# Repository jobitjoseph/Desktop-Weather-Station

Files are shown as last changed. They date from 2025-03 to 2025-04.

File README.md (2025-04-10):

# [Desktop-Weather-Station](https://circuitdigest.com/microcontroller-projects/)

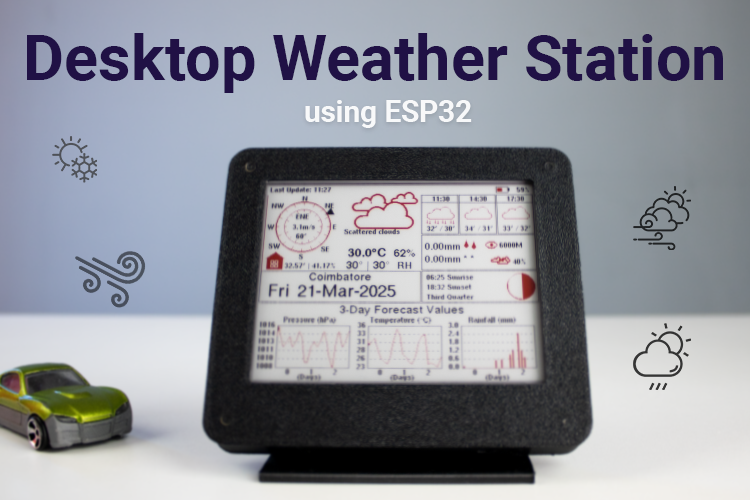
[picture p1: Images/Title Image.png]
Main Image


---
<p>
  In today’s fast-paced world, many of us spend long hours indoors—whether working from home, studying, or just managing our daily routines. Natural cues like changing skies, outdoor temperatures, or the feel of humidity are often lost behind four walls and closed windows. This can make it difficult to stay aware of what’s happening outside, especially when our focus is tied to digital devices. Having a dedicated, always-visible weather display on your desk adds a subtle but meaningful connection to the outside world. It’s a small touch that can help with planning your day, knowing when to grab a jacket before stepping out, or simply enjoying the gentle reminder that time and weather continue to change beyond the screen.
</p>

<p>This project offers a practical way to build a clean and minimal weather station using an ESP32 microcontroller and an E-Ink display. The use of E-Ink ensures that the display remains readable even without constant power, making it a perfect fit for battery-powered desktop use. Once connected to Wi-Fi, the station fetches real-time weather data such as temperature, humidity, and current conditions using the OpenWeatherMap API. It also monitors indoor temperature and humidity with the help of a built-in sensor and adds to the data displayed on the screen. The device automatically updates itself at fixed intervals and enters deep sleep to conserve energy. Once assembled, it becomes a quiet and elegant companion on your desk—keeping you informed, without the distractions of a smartphone or computer screen.</p>

The firmware part of this project builds upon the excellent work of [David Bird](https://github.com/G6EJD/ESP32-e-Paper-Weather-Display). The code has been adapted from his original implementation.

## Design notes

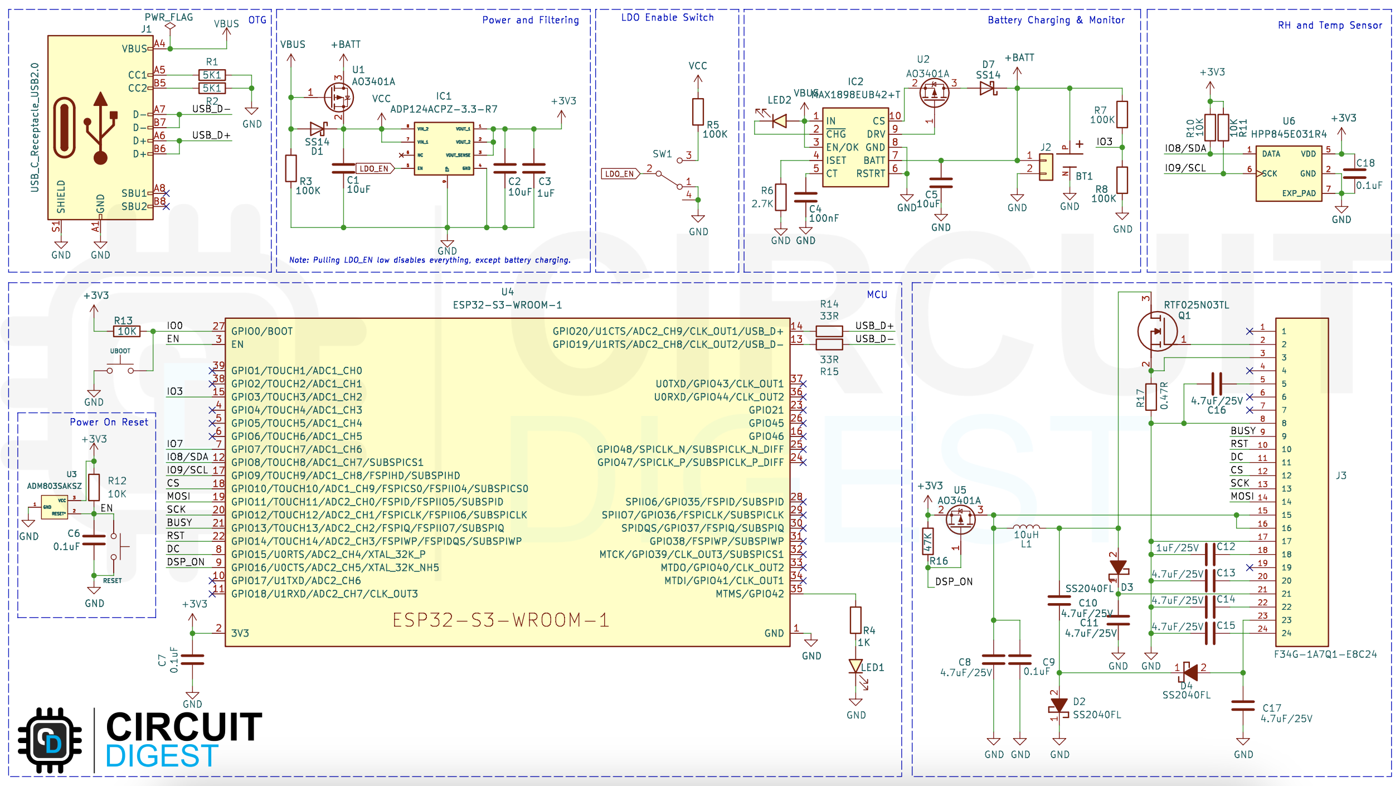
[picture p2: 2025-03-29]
Images/Desktop Weather Station Schematics.png

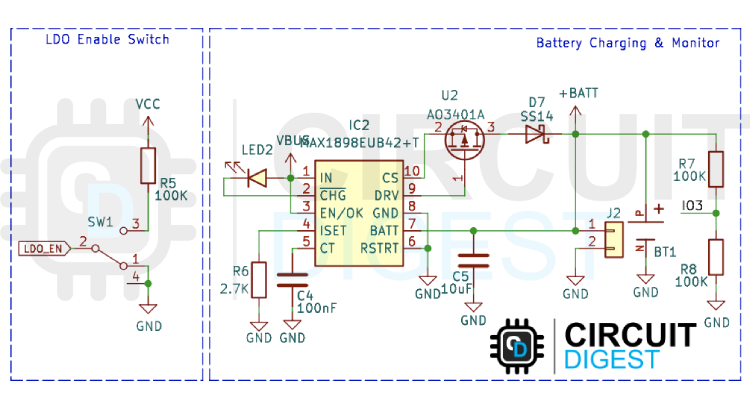
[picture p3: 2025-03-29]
Images/Desktop Weather Station Power Switch and Battery Management.png

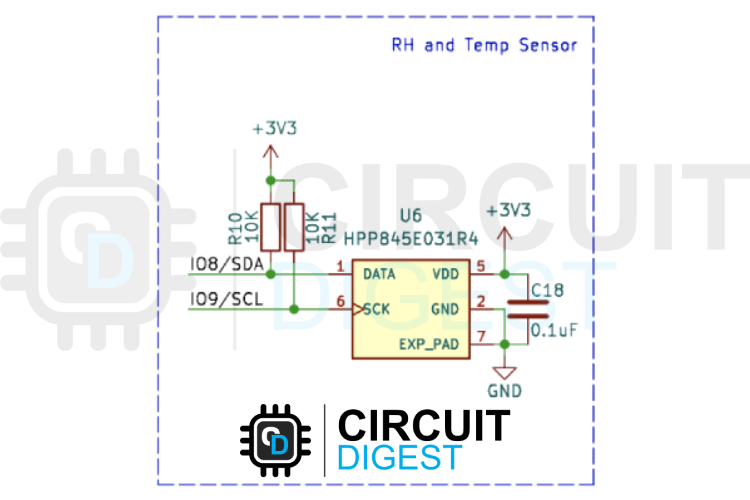
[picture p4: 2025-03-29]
Images/Desktop Weather Station Temperature and Humidity Sensor (1) (1).png

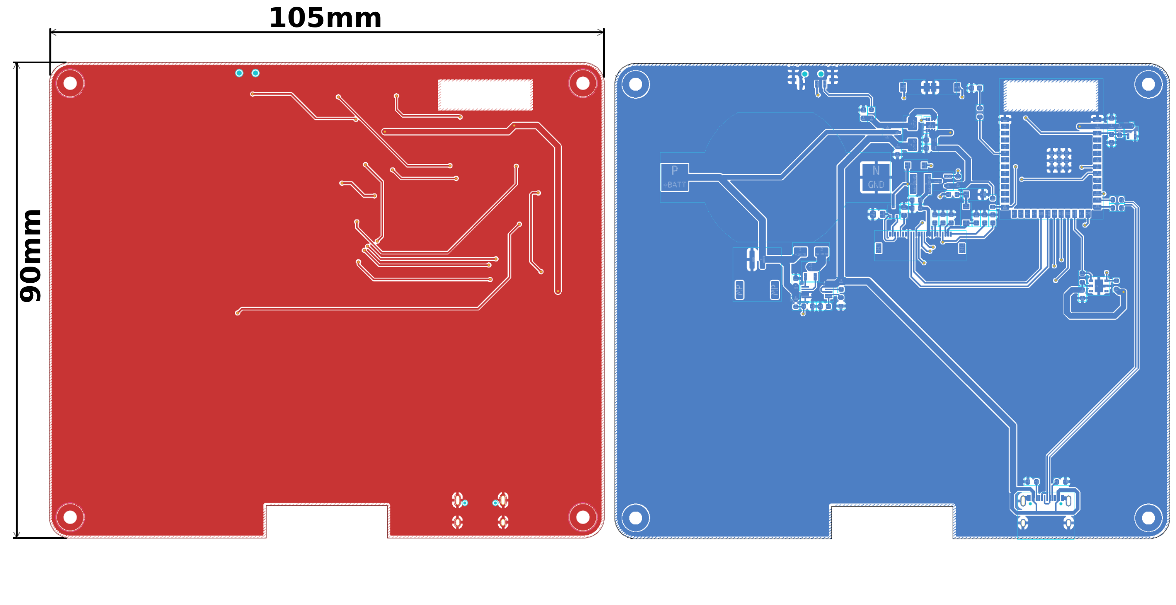
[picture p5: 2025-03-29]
Images/Desktop weather station PCB layers.png

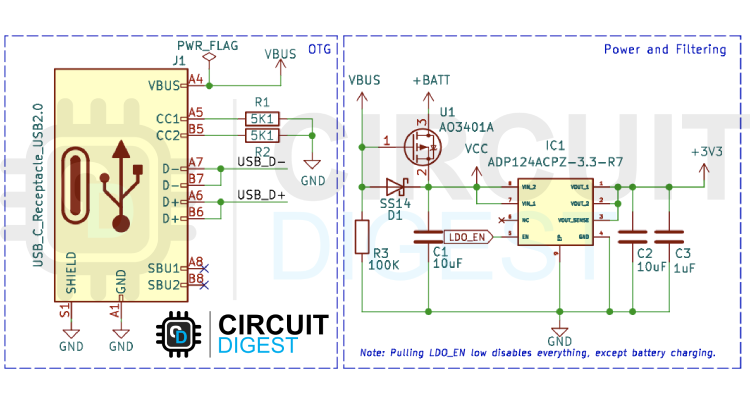
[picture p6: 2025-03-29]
Images/Desktop Weather Station USB Input and Power Management.png

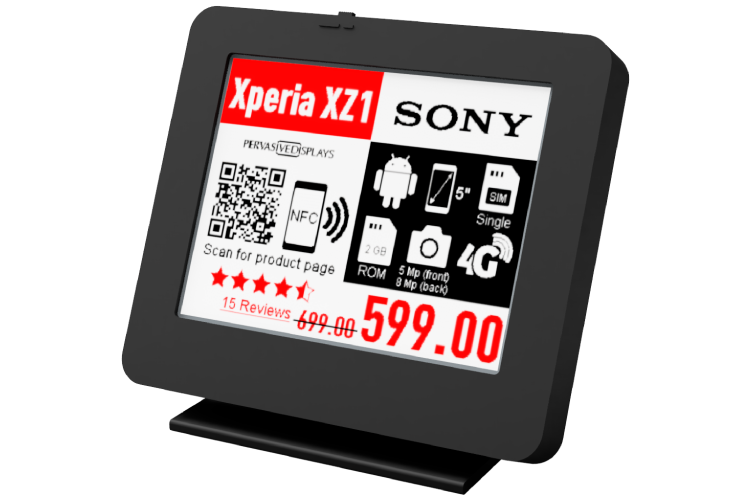
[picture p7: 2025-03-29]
Images/Desktop Weather Station 3D.png

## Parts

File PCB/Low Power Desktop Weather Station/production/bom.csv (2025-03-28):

Designator | Footprint | Quantity | Value | LCSC Part #
BOOT1 | Tactile 3x4x2mm TS-A010 | 1 | RESET
BOOT2 | Tactile 3x4x2mm TS-A010 | 1 | UBOOT
BT1 | BAT_BU2450SM-JJ-G | 1 | BU2450SM-JJ-G
C1, C2, C5 | 0603 | 3 | 10uF
C10, C11, C13, C14, C15, C16, C17, C8 | 0603 | 8 | 4.7uF/25V
C12 | 0603 | 1 | 1uF/25V
C18, C6, C7 | 0603 | 3 | 0.1uF
C3 | 0603 | 1 | 1uF
C4 | 0603 | 1 | 100nF
C9 | 0603 | 1 | 0.1uF
D1, D7 | D_SMA | 2 | SS14
D2, D3, D4 | SODFL3618X110N | 3 | SS2040FL
IC1 | SON50P200X200X65-9N-D | 1 | ADP124ACPZ-3.3-R7
IC2 | SOP50P490X110-10N | 1 | MAX1898EUB42+T
J1 | USB_C_Receptacle_XKB_U262-16XN-4BVC11 | 1 | USB_C_Receptacle_USB2.0
J2 | JST_PH_S2B-PH-SM4-TB_1x02-1MP_P2.00mm_Horizontal | 1 | B2B-PH-SM4-TB(LF)(SN)
J3 | AMPHENOL_F34G-1A7Q1-E8C24 | 1 | F34G-1A7Q1-E8C24
L1 | L_Taiyo-Yuden_MD-4040 | 1 | 10uH
LED1 | 0603 | 1 | LED Red
LED2 | 0603 | 1 | LED Blue
Q1 | RTF025N03TL | 1 | RTF025N03TL
R1, R2 | 0603 | 2 | 5K1
R10, R11, R12, R13 | 0603 | 4 | 10K
R14, R15 | 0603 | 2 | 33R
R16 | 0603 | 1 | 47K
R17 | 0805 | 1 | 0.47R
R3, R5, R7, R8 | 0603 | 4 | 100K
R4 | 0603 | 1 | 1K
R6 | 0603 | 1 | 2.7K
SW1 | slide switch spdt | 1 | SLW-66527511-SMT-TR
U1, U2, U5 | SOT-23 | 3 | AO3401A
U3 | KS_3_ADI | 1 | ADM803SAKSZ
U4 | ESP32-S3-WROOM-1 | 1 | ESP32-S3-WROOM-1
U6 | SON100P300X300X90-7N | 1 | HPP845E031R4

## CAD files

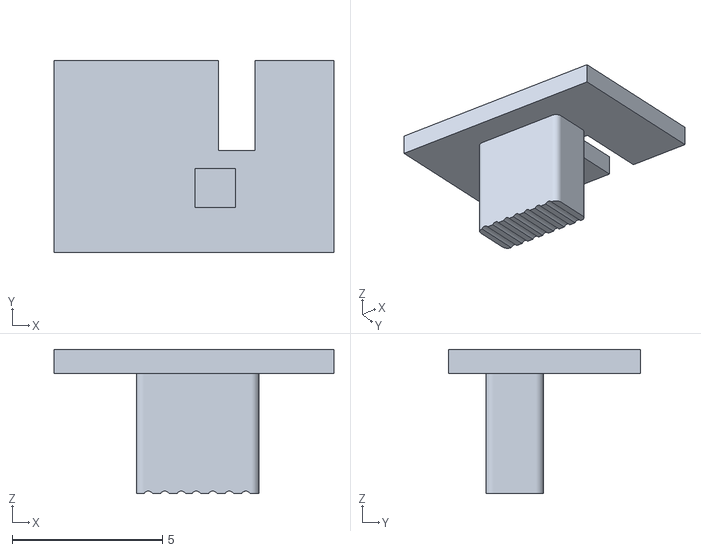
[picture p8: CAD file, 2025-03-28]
Enclosure STL Files/Switch.stl
9.33 x 6.39 x 4.80

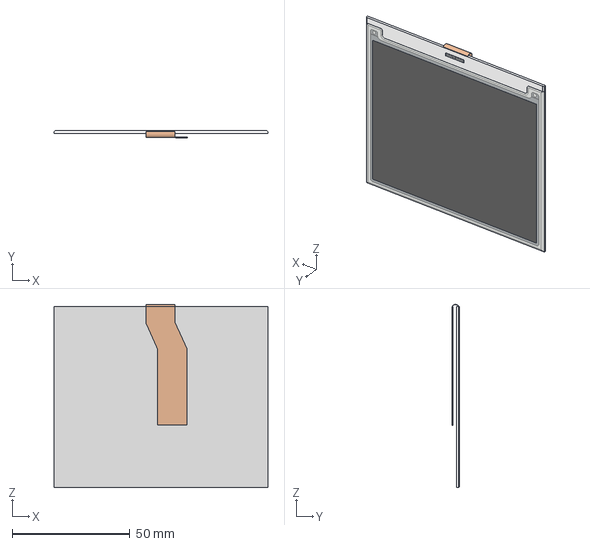
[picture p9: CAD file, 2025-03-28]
PCB/Low Power Desktop Weather Station/4.2 E-Ink - Display folded cable v3.step
91.0 x 3.18 x 77.9 mm

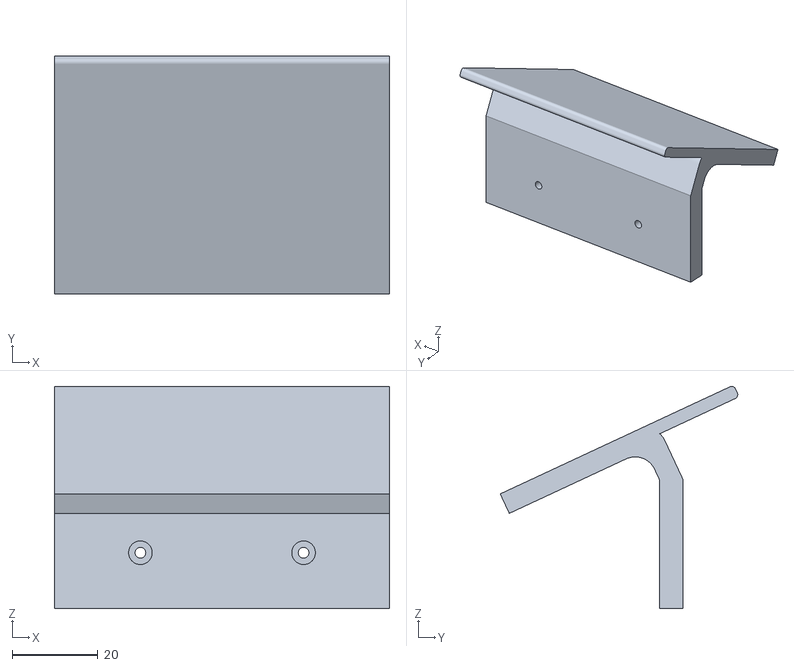
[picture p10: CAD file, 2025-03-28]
Enclosure STL Files/Stand_V2.stl
78.0 x 55.3 x 51.7

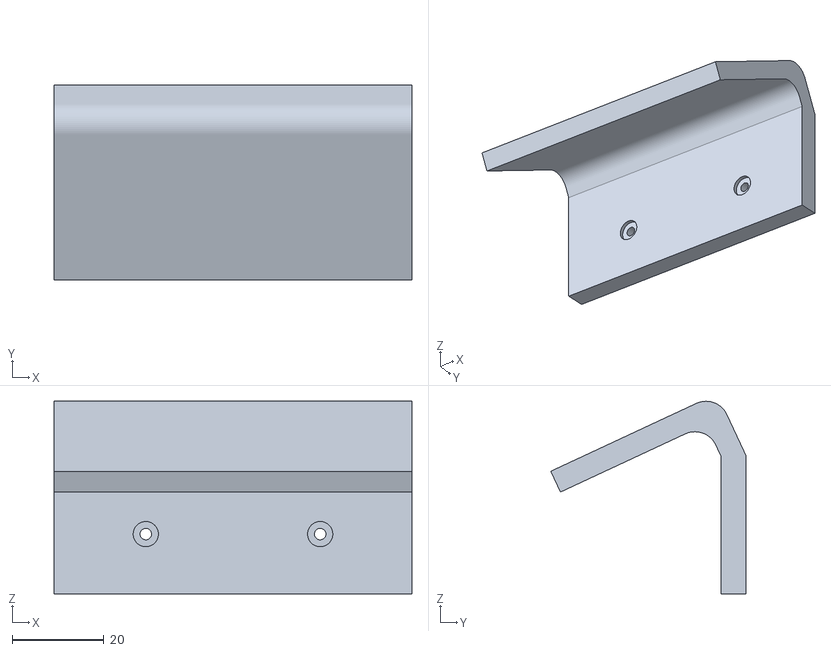
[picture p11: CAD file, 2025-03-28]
Enclosure STL Files/Stand.stl
78.0 x 42.6 x 41.9

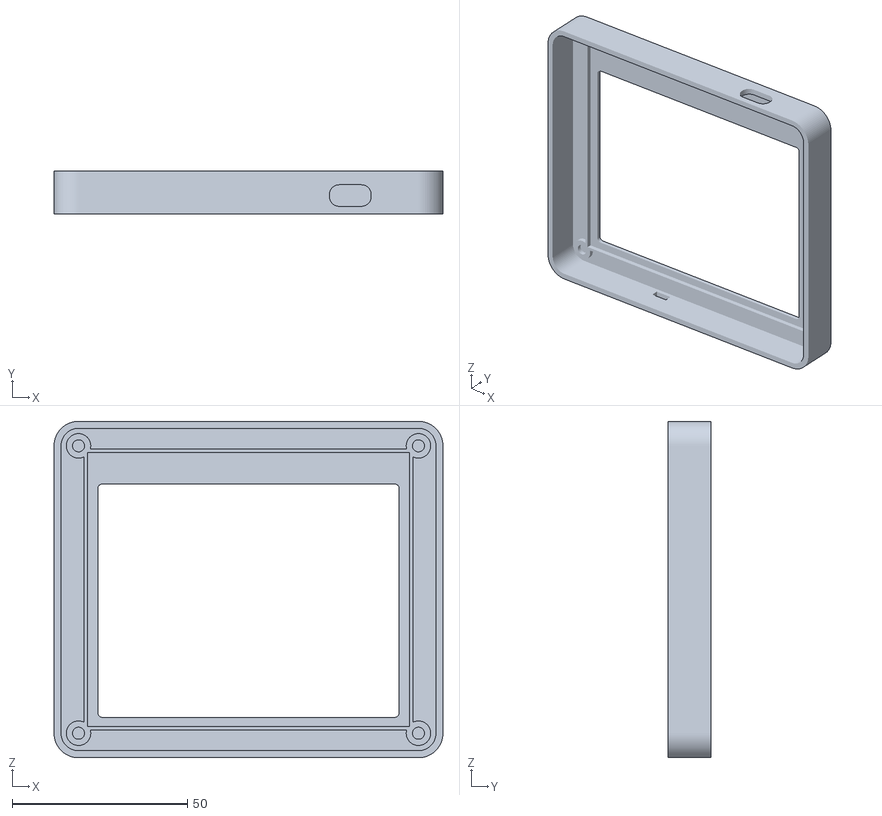
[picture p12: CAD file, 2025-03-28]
Enclosure STL Files/Top.stl
111.0 x 12.4 x 96.0

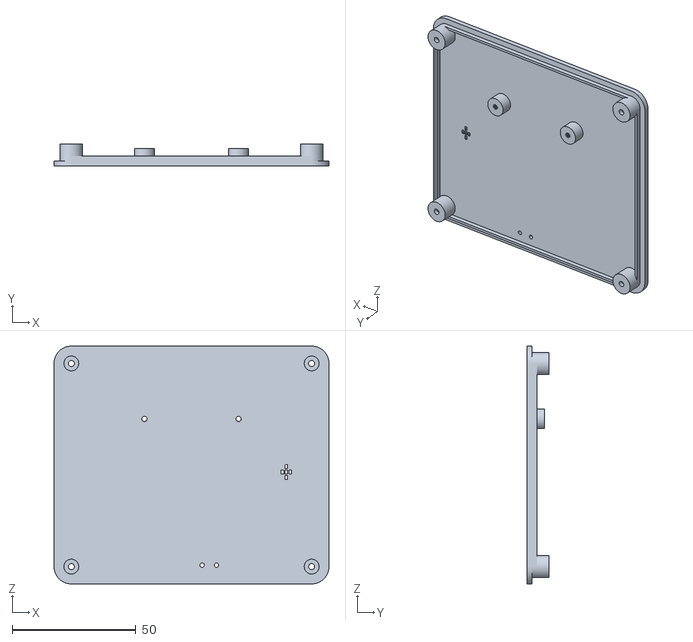
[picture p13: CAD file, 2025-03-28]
Enclosure STL Files/Bottom.stl
111.0 x 8.85 x 96.0

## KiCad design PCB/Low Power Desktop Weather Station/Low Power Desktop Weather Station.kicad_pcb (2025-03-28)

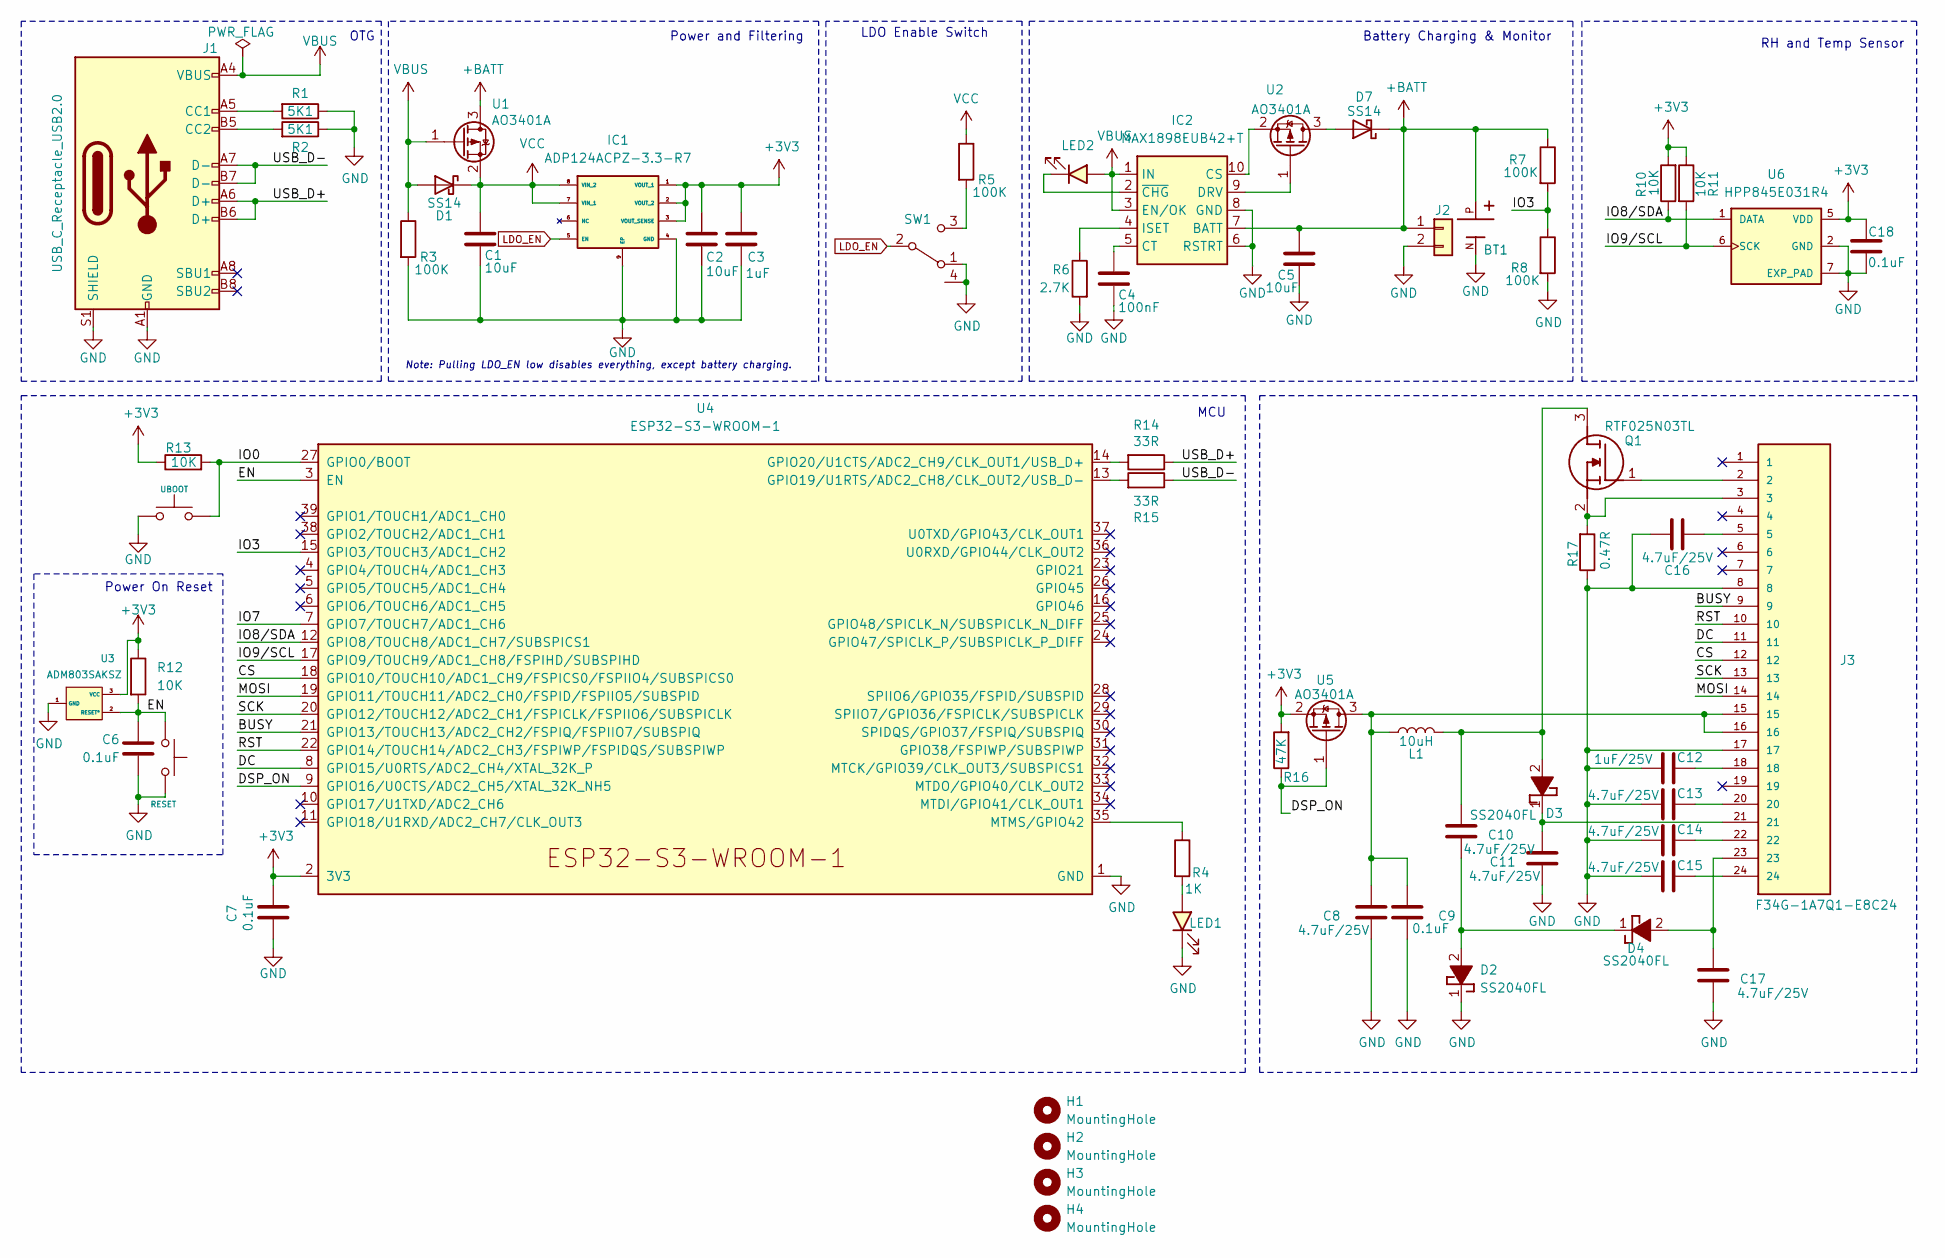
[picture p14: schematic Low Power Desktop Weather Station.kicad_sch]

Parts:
BOOT1: RESET; Tactile 3x4x2mm TS-A010; DigiKey Part Number 2449-CS1213AGF160CT-ND
BOOT2: UBOOT; Tactile 3x4x2mm TS-A010; DigiKey Part Number 2449-CS1213AGF160CT-ND
BT1: BU2450SM-JJ-G; BAT_BU2450SM-JJ-G; PARTREV J
C1: 10uF; C_0603_1608Metric; DigiKey Part Number 1276-1038-1-ND
C2, C5: 10uF; C_0603_1608Metric; DigiKey Part Number 490-10692-1-ND
C3: 1uF; C_0603_1608Metric; DigiKey Part Number 490-10018-1-ND
C4: 100nF; C_0603_1608Metric; DigiKey Part Number 490-10692-1-ND
C6, C7, C18: 0.1uF; C_0603_1608Metric; DigiKey Part Number 490-6328-1-ND
C8, C10, C11, C13, C14, C15, C16, C17: 4.7uF/25V; C_0603_1608Metric
C9: 0.1uF; C_0603_1608Metric
C12: 1uF/25V; C_0603_1608Metric
D1: SS14; D_SMA; DigiKey Part Number SS14-M3/5ATGICT-ND
D2, D3, D4: SS2040FL; SODFL3618X110N; Mouser Part Number 241-SS2040FLR100001
D7: SS14; D_SMA
H1, H2, H3, H4: MountingHole; MountingHole_2.5mm_Pad
IC1: ADP124ACPZ-3.3-R7; SON50P200X200X65-9N-D; Mouser Part Number 584-ADP124ACPZ-3.3R7
IC2: MAX1898EUB42+T; SOP50P490X110-10N; DigiKey Part Number MAX1898EUB42+TCT-ND
J1: USB_C_Receptacle_USB2.0; USB_C_Receptacle_XKB_U262-16XN-4BVC11; DigiKey Part Number 2073-USB4105-GF-ACT-ND
J2: B2B-PH-SM4-TB(LF)(SN); JST_PH_S2B-PH-SM4-TB_1x02-1MP_P2.00mm_Horizontal; DigiKey Part Number 455-1704-ND
J3: F34G-1A7Q1-E8C24; AMPHENOL_F34G-1A7Q1-E8C24; PARTREV A
L1: 10uH; L_Taiyo-Yuden_MD-4040
LED1: LED Red; LED_0603_1608Metric; DigiKey Part Number 3147-B1911USD-20D000114U1930CT-ND
LED2: LED Blue; LED_0603_1608Metric; DigiKey Part Number 3147-B1911NB--20C005314U1930CT-ND
Q1: RTF025N03TL; Mouser Part Number 755-RTF025N03TL
R1, R2: 5K1; R_0603_1608Metric; DigiKey Part Number P5.10KHCT-ND
R3, R5, R7, R8: 100K; R_0603_1608Metric; DigiKey Part Number P100KHCT-ND
R4: 1K; R_0603_1608Metric; DigiKey Part Number P1.00KHCT-ND
R6: 2.7K; R_0603_1608Metric; DigiKey Part Number P1.40KHCT-ND
R10, R11, R12, R13: 10K; R_0603_1608Metric; DigiKey Part Number P10.0KHCT-ND
R14, R15: 33R; R_0603_1608Metric; DigiKey Part Number P17467CT-ND
R16: 47K; R_0603_1608Metric; DigiKey Part Number P10.0KHCT-ND
R17: 0.47R; R_0805_2012Metric; DigiKey Part Number P17467CT-ND
SW1: SLW-66527511-SMT-TR; slide switch spdt; DigiKey Part Number 2223-SLW-66527511-SMT-TRCT-ND
U1, U2, U5: AO3401A; SOT-23; DigiKey Part Number AO3401-ND
U3: ADM803SAKSZ; KS_3_ADI; DigiKey Part Number 505-ADM803SAKSZ-REEL7CT-ND
U4: ESP32-S3-WROOM-1; DigiKey Part Number 1965-ESP32-S3-WROOM-1-N16R8CT-ND
U6: HPP845E031R4; SON100P300X300X90-7N; PARTREV 8

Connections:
+3V3: C2.1, C3.1, C7.1, C18.1, IC1.1 (VOUT_1), IC1.2 (VOUT_2), IC1.3 (VOUT_SENSE), R10.2, R11.1, R12.1, R13.1, R16.2, U3.3 (VCC), U4.2 (3V3), U5.2 (S), U6.5 (VDD)
+BATT: BT1.P, C5.1, D7.1 (K), IC2.7 (BATT), J2.1, R7.1, U1.3 (D)
/BUSY: J3.9, U4.21 (GPIO13/TOUCH13/ADC2_CH2/FSPIQ/FSPIIO7/S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)
/CS: J3.12, U4.18 (GPIO10/TOUCH10/ADC1_CH9/FSPICS0/FSPIIO4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)
/DC: J3.11, U4.8 (GPIO15/U0RTS/ADC2_CH4/XTAL_32K_P)
/DSP_ON: R16.1, U4.9 (GPIO16/U0CTS/ADC2_CH5/XTAL_32K_NH5), U5.1 (G)
/EN: BOOT1.1, C6.1, R12.2, U3.2 (RESET*), U4.3 (EN)
/IO0: BOOT2.1, R13.2, U4.27 (GPIO0/BOOT)
/IO3: R7.2, R8.1, U4.15 (GPIO3/TOUCH3/ADC1_CH2)
/IO7: U4.7 (GPIO7/TOUCH7/ADC1_CH6)
/IO8/SDA: R10.1, U4.12 (GPIO8/TOUCH8/ADC1_CH7/SUBSPICS1), U6.1 (DATA)
/IO9/SCL: R11.2, U4.17 (GPIO9/TOUCH9/ADC1_CH8/FSPIHD/SUBSPIHD), U6.6 (SCK)
/MOSI: J3.14, U4.19 (GPIO11/TOUCH11/ADC2_CH0/FSPID/FSPIIO5/S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)
/RST: J3.10, U4.22 (GPIO14/TOUCH14/ADC2_CH3/FSPIWP/FSPIDQS/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)
/SCK: J3.13, U4.20 (GPIO12/TOUCH12/ADC2_CH1/FSPICLK/FSPIIO6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)
/USB_D+: J1.A6 (D+), J1.B6 (D+), R14.1
/USB_D-: J1.A7 (D-), J1.B7 (D-), R15.1
GND: BOOT1.2, BOOT2.2, BT1.N, C1.2, C2.2, C3.2, C4.2, C5.2, C6.2, C7.2, C8.2, C9.2, C11.2, C12.1, C13.1, C14.1, C15.1, C16.1, C17.2, C18.2, D2.1 (K), IC1.4 (GND), IC1.9 (EP), IC2.6 (RSTRT), IC2.8 (GND), J1.A1 (GND), J1.A12 (GND), J1.B1 (GND), J1.B12 (GND), J1.S1 (SHIELD), J2.2, J3.8, J3.17, LED1.1 (K), R1.1, R2.1, R3.2, R6.2, R8.2, R17.1, SW1.1 (A), SW1.4, U3.1 (GND), U4.1 (GND), U4.40 (GND), U4.41 (GND), U6.2 (GND), U6.7 (EXP_PAD)
LDO_EN: IC1.5 (EN), SW1.2 (B)
unnamed: C12.2, J3.18
unnamed: C13.2, J3.20
unnamed: C14.2, J3.22
unnamed: C15.2, J3.24
unnamed: C16.2, J3.5
unnamed: C10.2, D2.2 (A), D4.1 (K)
unnamed: C10.1, D3.2 (A), L1.2, Q1.3 (D)
unnamed: C11.1, D3.1 (K), J3.21
unnamed: C17.1, D4.2 (A), J3.23
unnamed: D7.2 (A), U2.3 (D)
unnamed: IC2.10 (CS), U2.2 (S)
unnamed: C4.1, IC2.5 (CT)
unnamed: IC2.9 (DRV), U2.1 (G)
unnamed: IC2.4 (ISET), R6.1
unnamed: IC2.2 (~CHG), LED2.1 (K)
unnamed: J1.A5 (CC1), R1.2
unnamed: J1.B5 (CC2), R2.2
unnamed: LED1.2 (A), R4.2
unnamed: J3.2, Q1.1 (G)
unnamed: J3.3, Q1.2 (S), R17.2
unnamed: R5.2, SW1.3 (C)
unnamed: R15.2, U4.13 (GPIO19/U1RTS/ADC2_CH8/CLK_OUT2/USB_D-)
unnamed: R14.2, U4.14 (GPIO20/U1CTS/ADC2_CH9/CLK_OUT1/USB_D+)
unnamed: R4.1, U4.35 (MTMS/GPIO42)
unnamed: C8.1, C9.1, J3.15, J3.16, L1.1, U5.3 (D)
VBUS: D1.2 (A), IC2.1 (IN), IC2.3 (EN/OK), J1.A4 (VBUS), J1.A9 (VBUS), J1.B4 (VBUS), J1.B9 (VBUS), LED2.2 (A), R3.1, U1.1 (G)
VCC: C1.1, D1.1 (K), IC1.7 (VIN_1), IC1.8 (VIN_2), R5.1, U1.2 (S)

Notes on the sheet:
MCU
Note: Pulling LDO_EN low disables everything, except battery charging.
RH and Temp Sensor
OTG
Power On Reset
Battery Charging & Monitor
Power and Filtering
LDO Enable Switch

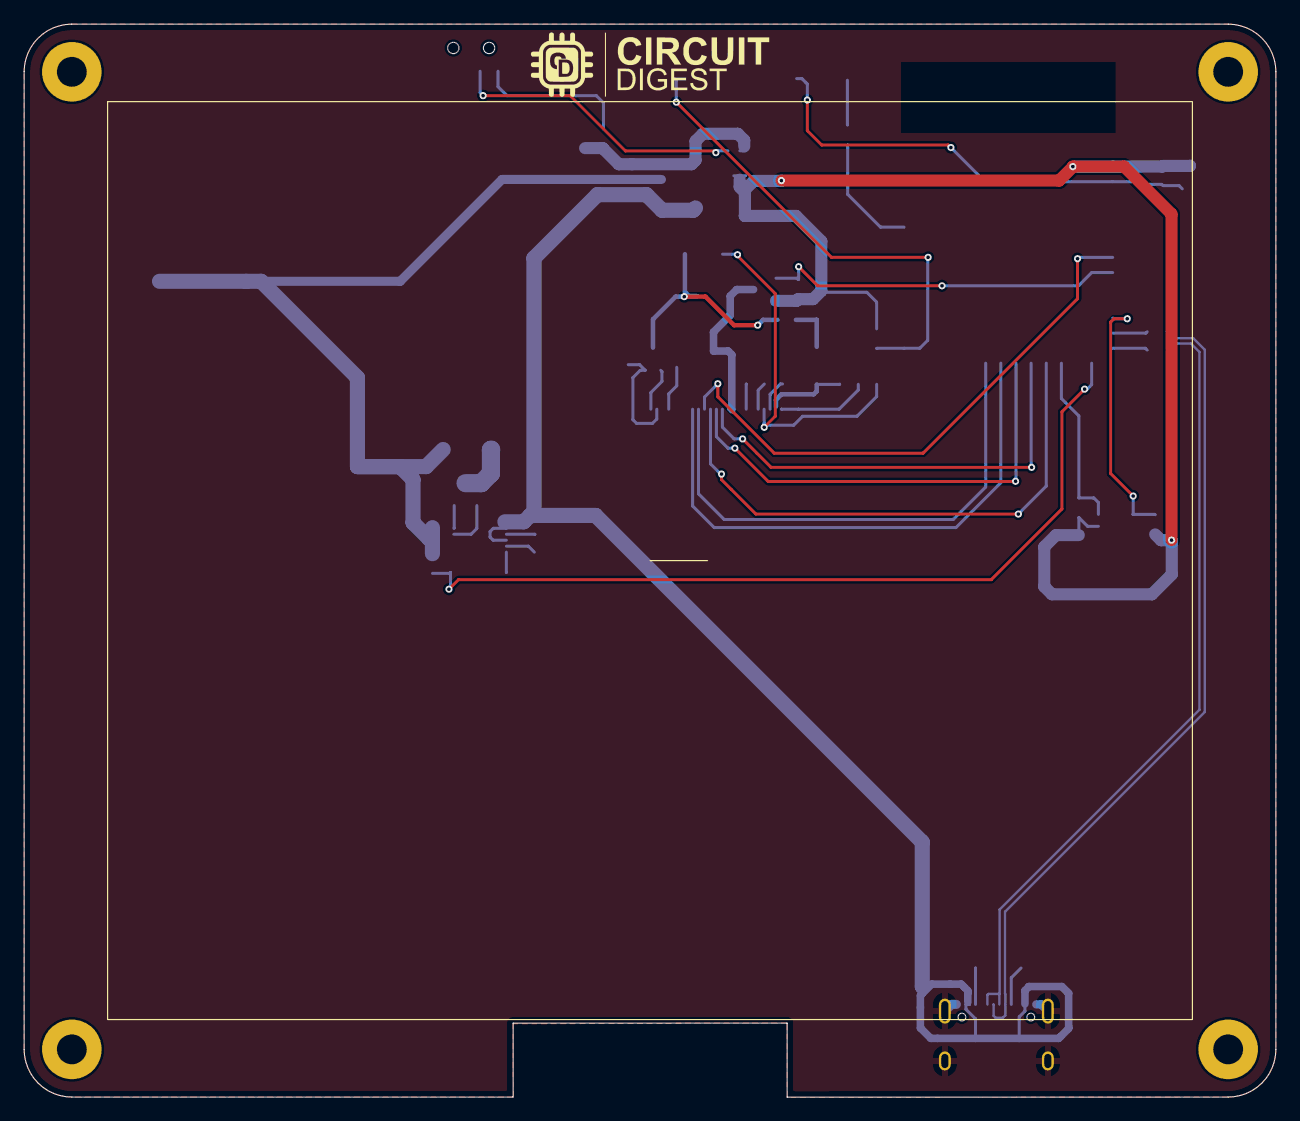
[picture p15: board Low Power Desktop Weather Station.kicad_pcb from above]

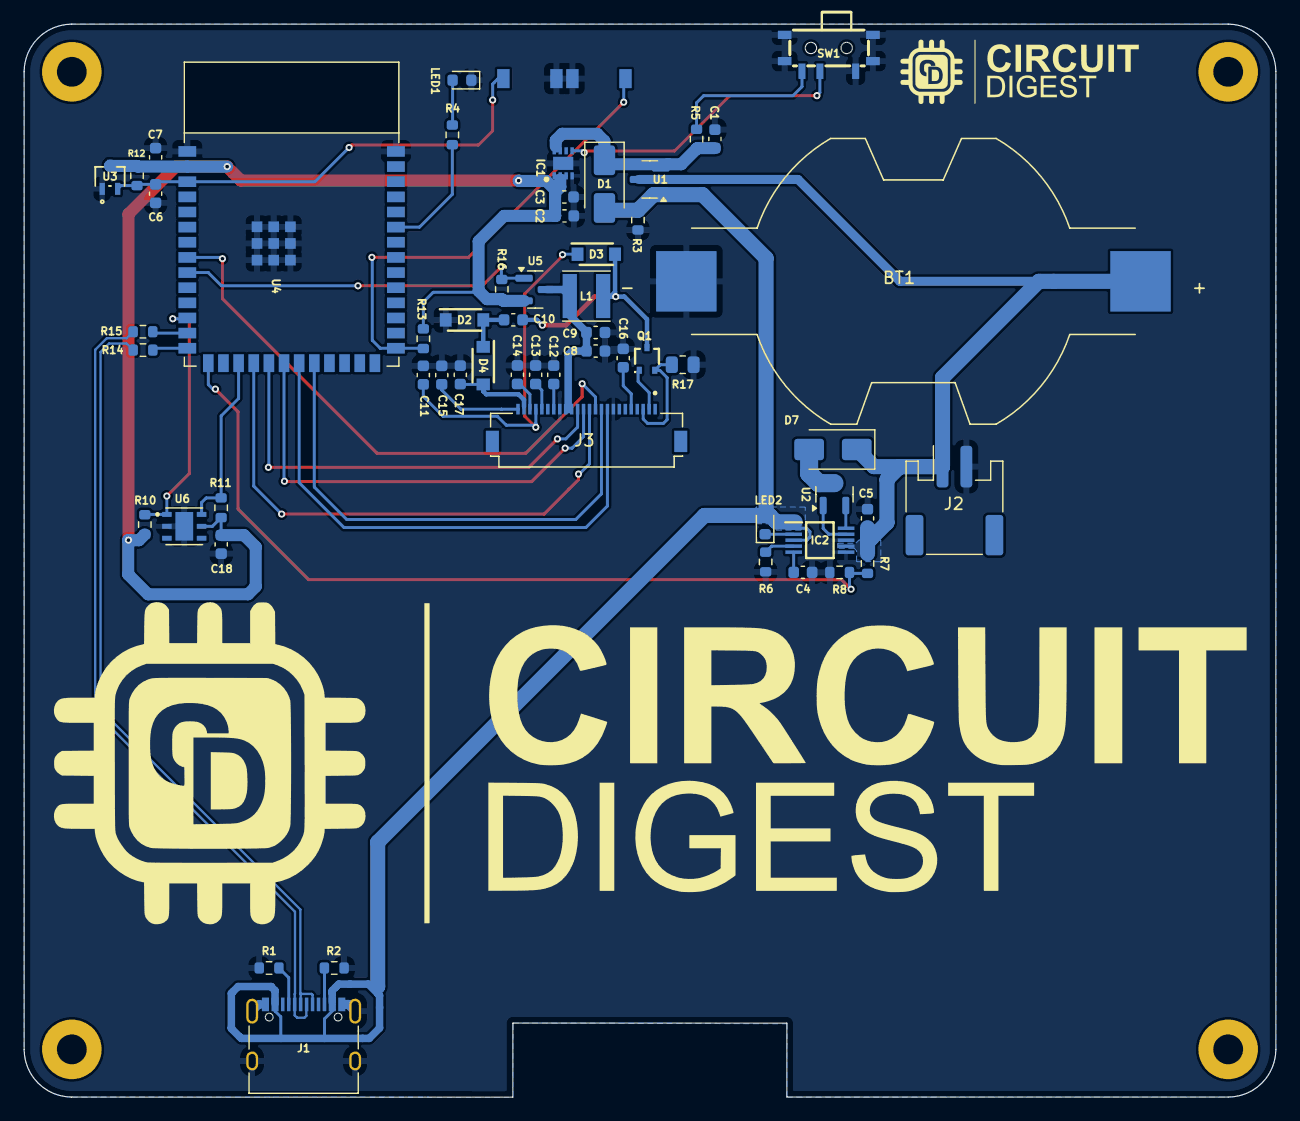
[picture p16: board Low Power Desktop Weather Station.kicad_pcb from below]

Board: 2 copper layers, 105.0 x 90.0 mm, 62 parts (57 on the bottom side), 45 nets.

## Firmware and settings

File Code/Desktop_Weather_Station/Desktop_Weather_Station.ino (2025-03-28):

#include "config.h"  // See 'config.h' file and enter your OWM API key and set the Wifi SSID and PASSWORD
#include <ArduinoJson.h>       // https://github.com/bblanchon/ArduinoJson
#include <WiFi.h>              // Built-in
#include "time.h"              // Built-in
#include <SPI.h>               // Built-in
#define  ENABLE_GxEPD2_display 0
#include <GxEPD2_BW.h>         // GxEPD2 v1.6.3
#include <GxEPD2_3C.h>
#include <U8g2_for_Adafruit_GFX.h>
#include "epaper_fonts.h"
#include "forecast_record.h"
#include "lang.h"
#include <Wire.h>
#define HTU21D_ADDRESS 0x40   // I2C address of HTU21D
#define TEMP_MEASURE_NO_HOLD  0xF3
#define HUMID_MEASURE_NO_HOLD 0xF5
#define SOFT_RESET            0xFE
#define USER_REGISTER_READ  0xE7
#define USER_REGISTER_WRITE 0xE6

#define SCREEN_WIDTH  400.0    // Set for landscape mode, don't remove the decimal place!
#define SCREEN_HEIGHT 300.0

enum alignment {LEFT, RIGHT, CENTER};

// Connections for the EPD Display
static const uint8_t EPD_BUSY = 13;  // to EPD BUSY
static const uint8_t EPD_CS   = 10;  // to EPD CS
static const uint8_t EPD_RST  = 14; // to EPD RST
static const uint8_t EPD_DC   = 15; // to EPD DC
static const uint8_t EPD_SCK  = 12; // to EPD CLK
static const uint8_t EPD_MISO = -1; // Master-In Slave-Out not used, as no data from display
static const uint8_t EPD_MOSI = 11; // to EPD DIN


GxEPD2_3C<GxEPD2_420c, GxEPD2_420c::HEIGHT> display(GxEPD2_420c(/*CS=5*/ EPD_CS, /*DC=*/ EPD_DC, /*RST=*/ EPD_RST, /*BUSY=*/ EPD_BUSY)); //
U8G2_FOR_ADAFRUIT_GFX u8g2Fonts;  // Select u8g2 font from here: https://github.com/olikraus/u8g2/wiki/fntlistall

// Using fonts:
// u8g2_font_helvB08_tf
// u8g2_font_helvB10_tf
// u8g2_font_helvB12_tf
// u8g2_font_helvB14_tf
// u8g2_font_helvB18_tf
// u8g2_font_helvB24_tf

boolean LargeIcon = true, SmallIcon = false;
#define Large  11           // For icon drawing, needs to be odd number for best effect
#define Small  5            // For icon drawing, needs to be odd number for best effect
String  time_str, date_str; // strings to hold time and received weather data
int     wifi_signal, CurrentHour = 0, CurrentMin = 0, CurrentSec = 0;
long    StartTime = 0;

//################ PROGRAM VARIABLES and OBJECTS ################

#define max_readings 24

Forecast_record_type  WxConditions[1];
Forecast_record_type  WxForecast[max_readings];

#include <common.h>

#define autoscale_on  true
#define autoscale_off false
#define barchart_on   true
#define barchart_off  false

float pressure_readings[max_readings]    = {0};
float temperature_readings[max_readings] = {0};
float humidity_readings[max_readings]    = {0};
float rain_readings[max_readings]        = {0};
float snow_readings[max_readings]        = {0};

long SleepDuration = 15; // Sleep time in minutes, aligned to the nearest minute boundary, so if 30 will always update at 00 or 30 past the hour

//#########################################################################################
void setup() {
  StartTime = millis();
  pinMode(16, OUTPUT);
  digitalWrite(16, LOW);
  pinMode(42, OUTPUT); 
  digitalWrite(42, HIGH);
  delay(100);
  Serial.begin(115200);
  Wire.begin();  // Initialize I2C
  softReset();  // Reset the sensor before starting
  disableHeater(); // Ensure the heater is turned off
  if (StartWiFi() == WL_CONNECTED && SetupTime() == true) {
    InitialiseDisplay(); // Give screen time to initialise by getting weather data!
    byte Attempts = 1;
    bool RxWeather = false, RxForecast = false;
    WiFiClient client;   // wifi client object
    while ((RxWeather == false || RxForecast == false) && Attempts <= 2) { // Try up-to 2 time for Weather and Forecast data
      if (RxWeather  == false) RxWeather  = obtain_wx_data(client, "weather");
      if (RxForecast == false) RxForecast = obtain_wx_data(client, "forecast");
      Attempts++;
    }
    if (RxWeather && RxForecast) { // Only if received both Weather or Forecast proceed
       StopWiFi(); // Reduces power consumption
      DisplayWeather();
      display.display(false); // Full screen update mode
    }
  }
  BeginSleep();
}
//#########################################################################################
void loop() { // this will never run!
yield();
}
//#########################################################################################
void BeginSleep() {
  display.powerOff();
  digitalWrite(16, HIGH);
  digitalWrite(42, LOW);
  long SleepTimer = SleepDuration * 60; // theoretical sleep duration
  long offset = (CurrentMin % SleepDuration) * 60 + CurrentSec; // number of seconds elapsed after last theoretical wake-up time point
  if (offset > SleepDuration/2 * 60){ // waking up too early will cause <offset> too large
    offset -= SleepDuration * 60; // then we should make it negative, so as to extend this coming sleep duration
  }
  esp_sleep_enable_timer_wakeup((SleepTimer - offset) * 1000000LL); // do compensation to cover ESP32 RTC timer source inaccuracies
  Serial.println("Entering " + String(SleepTimer) + "-secs of sleep time");
  Serial.println("Awake for : " + String((millis() - StartTime) / 1000.0, 3) + "-secs");
  Serial.println("Starting deep-sleep period...");
  esp_deep_sleep_start();      // Sleep for e.g. 30 minutes
}
//#########################################################################################
void DisplayWeather() {                 // 4.2" e-paper display is 400x300 resolution
  DrawHeadingSection();                 // Top line of the display
  DrawMainWeatherSection(172, 70);      // Centre section of display for Location, temperature, Weather report, current Wx Symbol and wind direction
  DrawForecastSection(233, 15);         // 3hr forecast boxes
  DisplayPrecipitationSection(233, 82); // Precipitation sectio
  if (WxConditions[0].Visibility > 0) Visibility(335, 100, String(WxConditions[0].Visibility) + "M");
  if (WxConditions[0].Cloudcover > 0) CloudCover(350, 125, WxConditions[0].Cloudcover);
  DrawAstronomySection(233, 74);        // Astronomy section Sun rise/set, Moon phase and Moon icon
}
//#########################################################################################
void DrawHeadingSection() {
  u8g2Fonts.setFont(u8g2_font_helvB08_tf);
  display.setTextColor(GxEPD_RED);
  drawString(SCREEN_WIDTH / 2, 2, City, CENTER);
  display.setTextColor(GxEPD_BLACK);
  drawString(4, 2, date_str, LEFT);
  drawString(120, 2, time_str, LEFT);
  DrawBattery(SCREEN_WIDTH-70, 14);
  display.drawLine(0, 14, SCREEN_WIDTH, 14, GxEPD_BLACK);
}
//#########################################################################################
void DrawMainWeatherSection(int x, int y) { 
  Display_HPP845E_Data(x - 120, y + 58);
  DisplayDisplayWindSection(x - 115, y - 3, WxConditions[0].Winddir, WxConditions[0].Windspeed, 40);
  DisplayWXicon(x + 5, y - 5, WxConditions[0].Icon, LargeIcon);
  u8g2Fonts.setFont(u8g2_font_helvB10_tf);
  u8g2Fonts.setFont(u8g2_font_helvB12_tf);
  String Wx_Description = WxConditions[0].Forecast0;
  if (WxConditions[0].Forecast1 != "") Wx_Description += " & " +  WxConditions[0].Forecast1;
  if (WxConditions[0].Forecast2 != "" && WxConditions[0].Forecast1 != WxConditions[0].Forecast2) Wx_Description += " & " +  WxConditions[0].Forecast2;
  drawStringMaxWidth(x - 170, y + 83, 28, TitleCase(Wx_Description), LEFT);
  DrawMainWx(x, y + 60);
  display.drawRect(0, y + 68, 232, 48, GxEPD_BLACK);
}
//#########################################################################################
void DrawForecastSection(int x, int y) {
  u8g2Fonts.setFont(u8g2_font_helvB10_tf);
  DrawForecastWeather(x, y, 0);
  DrawForecastWeather(x + 56, y, 1);
  DrawForecastWeather(x + 112, y, 2);
  //       (x,y,width,height,MinValue, MaxValue, Title, Data Array, AutoScale, ChartMode)
  for (int r = 0; r < max_readings; r++) {
    if (Units == "I") {
      pressure_readings[r] = WxForecast[r].Pressure * 0.02953;
      rain_readings[r]     = WxForecast[r].Rainfall * 0.0393701;
    }
    else {
      pressure_readings[r] = WxForecast[r].Pressure;
      rain_readings[r]     = WxForecast[r].Rainfall;
    }
    temperature_readings[r] = WxForecast[r].Temperature;
  }
  display.drawLine(0, y + 172, SCREEN_WIDTH, y + 172, GxEPD_BLACK);
  u8g2Fonts.setFont(u8g2_font_helvB12_tf);
  drawString(SCREEN_WIDTH / 2, y + 180, TXT_FORECAST_VALUES, CENTER);
  u8g2Fonts.setFont(u8g2_font_helvB10_tf);
  DrawGraph(SCREEN_WIDTH / 400 * 30,  SCREEN_HEIGHT / 300 * 221, SCREEN_WIDTH / 4, SCREEN_HEIGHT / 5, 900, 1050, Units == "M" ? TXT_PRESSURE_HPA : TXT_PRESSURE_IN, pressure_readings, max_readings, autoscale_on, barchart_off);
  DrawGraph(SCREEN_WIDTH / 400 * 158, SCREEN_HEIGHT / 300 * 221, SCREEN_WIDTH / 4, SCREEN_HEIGHT / 5, 10, 30, Units == "M" ? TXT_TEMPERATURE_C : TXT_TEMPERATURE_F, temperature_readings, max_readings, autoscale_on, barchart_off);
  DrawGraph(SCREEN_WIDTH / 400 * 288, SCREEN_HEIGHT / 300 * 221, SCREEN_WIDTH / 4, SCREEN_HEIGHT / 5, 0, 30, Units == "M" ? TXT_RAINFALL_MM : TXT_RAINFALL_IN, rain_readings, max_readings, autoscale_on, barchart_on);
}
//#########################################################################################
void DrawForecastWeather(int x, int y, int index) {
  u8g2Fonts.setFont(u8g2_font_helvB08_tf);
  display.drawRect(x, y, 55, 65, GxEPD_BLACK);
  display.drawLine(x + 1, y + 13, x + 54, y + 13, GxEPD_BLACK);
  DisplayWXicon(x + 28, y + 35, WxForecast[index].Icon, SmallIcon);
  drawString(x + 31, y + 3, String(ConvertUnixTime(WxForecast[index].Dt + WxConditions[0].Timezone).substring(0,5)), CENTER);
  drawString(x + 41, y + 52, String(WxForecast[index].High, 0) + "° / " + String(WxForecast[index].Low, 0) + "°", CENTER);
}
//#########################################################################################
void DrawMainWx(int x, int y) {
  u8g2Fonts.setFont(u8g2_font_helvB14_tf);
  drawString(x - 25, y - 22, String(WxConditions[0].Temperature, 1) + "°" + (Units == "M" ? "C" : "F"), CENTER); // Show current Temperature
  u8g2Fonts.setFont(u8g2_font_helvB12_tf);
  drawString(x - 15, y - 3, String(WxConditions[0].High, 0) + "° | " + String(WxConditions[0].Low, 0) + "°", CENTER); // Show forecast high and Low
  drawString(x + 30, y - 22, String(WxConditions[0].Humidity, 0) + "%", CENTER);
  u8g2Fonts.setFont(u8g2_font_helvB10_tf);
  drawString(x + 32, y - 3, "RH", CENTER);
}
//#########################################################################################
void DisplayDisplayWindSection(int x, int y, float angle, float windspeed, int Cradius) {
  arrow(x, y, Cradius - 7, angle, 12, 18); // Show wind direction on outer circle of width and length
  u8g2Fonts.setFont(u8g2_font_helvB08_tf);
  int dxo, dyo, dxi, dyi;
  display.drawLine(0, 15, 0, y + Cradius + 30, GxEPD_RED);
  display.drawCircle(x, y, Cradius, GxEPD_RED);     // Draw compass circle
  display.drawCircle(x, y, Cradius + 1, GxEPD_RED); // Draw compass circle
  display.drawCircle(x, y, Cradius * 0.7, GxEPD_RED); // Draw compass inner circle
  for (float a = 0; a < 360; a = a + 22.5) {
    dxo = Cradius * cos((a - 90) * PI / 180);
    dyo = Cradius * sin((a - 90) * PI / 180);
    if (a == 45)  drawString(dxo + x + 10, dyo + y - 10, TXT_NE, CENTER);
    if (a == 135) drawString(dxo + x + 7,  dyo + y + 5,  TXT_SE, CENTER);
    if (a == 225) drawString(dxo + x - 15, dyo + y,      TXT_SW, CENTER);
    if (a == 315) drawString(dxo + x - 15, dyo + y - 10, TXT_NW, CENTER);
    dxi = dxo * 0.9;
    dyi = dyo * 0.9;
    display.drawLine(dxo + x, dyo + y, dxi + x, dyi + y, GxEPD_RED);
    dxo = dxo * 0.7;
    dyo = dyo * 0.7;
    dxi = dxo * 0.9;
    dyi = dyo * 0.9;
    display.drawLine(dxo + x, dyo + y, dxi + x, dyi + y, GxEPD_RED);
  }
  drawString(x, y - Cradius - 10,     TXT_N, CENTER);
  drawString(x, y + Cradius + 5,      TXT_S, CENTER);
  drawString(x - Cradius - 10, y - 3, TXT_W, CENTER);
  drawString(x + Cradius + 8,  y - 3, TXT_E, CENTER);
  drawString(x - 2, y - 20, WindDegToDirection(angle), CENTER);
  drawString(x + 3, y + 12, String(angle, 0) + "°", CENTER);
  drawString(x + 3, y - 3, String(windspeed, 1) + (Units == "M" ? "m/s" : "mph"), CENTER);
}
//#########################################################################################
String WindDegToDirection(float winddirection) {
  int dir = int((winddirection / 22.5) + 0.5);
  String Ord_direction[16] = {TXT_N, TXT_NNE, TXT_NE, TXT_ENE, TXT_E, TXT_ESE, TXT_SE, TXT_SSE, TXT_S, TXT_SSW, TXT_SW, TXT_WSW, TXT_W, TXT_WNW, TXT_NW, TXT_NNW};
  return Ord_direction[(dir % 16)];
}
//#########################################################################################
void Display_HPP845E_Data(int x, int y) {
  display.fillRect(x-45, y-10 , 24, 18, GxEPD_RED);
  display.fillTriangle(x - 47, y - 10, x - 33, y - 20, x - 20, y - 10, GxEPD_RED);
  //display.fillRect(x - 30, y + 2, 6, 6, GxEPD_WHITE);
  display.drawRect(x - 39, y , 5, 5, GxEPD_WHITE);
  display.drawRect(x - 33, y , 5, 5, GxEPD_WHITE);
  display.drawRect(x - 39, y - 6, 5, 5, GxEPD_WHITE);
  display.drawRect(x - 33, y - 6, 5, 5, GxEPD_WHITE);
  float temperature = readTemperature();
  float humidity = readHumidity();
  drawString(x+30, y-2, String(temperature)+"° | "+String(humidity)+"%", CENTER);
  
}
//#########################################################################################
void DisplayPrecipitationSection(int x, int y) {
  display.drawRect(x, y - 1, 167, 56, GxEPD_BLACK); // precipitation outline
  u8g2Fonts.setFont(u8g2_font_helvB10_tf);
  if (WxForecast[1].Rainfall > 0.005) { // Ignore small amounts
    drawString(x + 5, y + 15, String(WxForecast[1].Rainfall, 2) + (Units == "M" ? "mm" : "in"), LEFT); // Only display rainfall total today if > 0
    addraindrop(x + 65 - (Units == "I" ? 10 : 0), y + 16, 7);
  }
  if (WxForecast[1].Snowfall > 0.005)  // Ignore small amounts
    drawString(x + 5, y + 35, String(WxForecast[1].Snowfall, 2) + (Units == "M" ? "mm" : "in") + " * *", LEFT); // Only display snowfall total today if > 0
}
//#########################################################################################
void DrawAstronomySection(int x, int y) {
  u8g2Fonts.setFont(u8g2_font_helvB08_tf);
  display.drawRect(x, y + 64, 167, 48, GxEPD_BLACK);
  drawString(x + 7, y + 70, ConvertUnixTime(WxConditions[0].Sunrise + WxConditions[0].Timezone).substring(0, (Units == "M" ? 5 : 7)) + " " + TXT_SUNRISE, LEFT);
  drawString(x + 7, y + 85, ConvertUnixTime(WxConditions[0].Sunset + WxConditions[0].Timezone).substring(0, (Units == "M" ? 5 : 7)) + " " + TXT_SUNSET, LEFT);
  time_t now = time(NULL);
  struct tm * now_utc = gmtime(&now);
  const int day_utc   = now_utc->tm_mday;
  const int month_utc = now_utc->tm_mon + 1;
  const int year_utc  = now_utc->tm_year + 1900;
  drawString(x + 7, y + 100, MoonPhase(day_utc, month_utc, year_utc), LEFT);
  DrawMoon(x + 105, y + 50, day_utc, month_utc, year_utc, Hemisphere);
}
//#########################################################################################
void DrawMoon(int x, int y, int dd, int mm, int yy, String hemisphere) {
  const int diameter = 38;
  double Phase = NormalizedMoonPhase(dd, mm, yy);
  hemisphere.toLowerCase();
  if (hemisphere == "south") Phase = 1 - Phase;
  // Draw dark part of moon
  display.fillCircle(x + diameter - 1, y + diameter, diameter / 2 + 1, GxEPD_RED);
  const int number_of_lines = 90;
  for (double Ypos = 0; Ypos <= 45; Ypos++) {
    double Xpos = sqrt(45 * 45 - Ypos * Ypos);
    // Determine the edges of the lighted part of the moon
    double Rpos = 2 * Xpos;
    double Xpos1, Xpos2;
    if (Phase < 0.5) {
      Xpos1 = - Xpos;
      Xpos2 = (Rpos - 2 * Phase * Rpos - Xpos);
    }
    else {
      Xpos1 = Xpos;
      Xpos2 = (Xpos - 2 * Phase * Rpos + Rpos);
    }
    // Draw light part of moon
    double pW1x = (Xpos1 + number_of_lines) / number_of_lines * diameter + x;
    double pW1y = (number_of_lines - Ypos)  / number_of_lines * diameter + y;
    double pW2x = (Xpos2 + number_of_lines) / number_of_lines * diameter + x;
    double pW2y = (number_of_lines - Ypos)  / number_of_lines * diameter + y;
    double pW3x = (Xpos1 + number_of_lines) / number_of_lines * diameter + x;
    double pW3y = (Ypos + number_of_lines)  / number_of_lines * diameter + y;
    double pW4x = (Xpos2 + number_of_lines) / number_of_lines * diameter + x;
    double pW4y = (Ypos + number_of_lines)  / number_of_lines * diameter + y;
    display.drawLine(pW1x, pW1y, pW2x, pW2y, GxEPD_WHITE);
    display.drawLine(pW3x, pW3y, pW4x, pW4y, GxEPD_WHITE);
  }
  display.drawCircle(x + diameter - 1, y + diameter, diameter / 2 + 1, GxEPD_RED);
}
//#########################################################################################
String MoonPhase(int d, int m, int y) {
  int c, e;
  double jd;
  int b;
  if (m < 3) {
    y--;
    m += 12;
  }
  ++m;
  c   = 365.25 * y;
  e   = 30.6  * m;
  jd  = c + e + d - 694039.09;     /* jd is total days elapsed */
  jd /= 29.53059;                  /* divide by the moon cycle (29.53 days) */
  b   = jd;                        /* int(jd) -> b, take integer part of jd */
  jd -= b;                         /* subtract integer part to leave fractional part of original jd */
  b   = jd * 8 + 0.5;              /* scale fraction from 0-8 and round by adding 0.5 */
  b   = b & 7;                     /* 0 and 8 are the same phase so modulo 8 for 0 */
  Hemisphere.toLowerCase();
  if (Hemisphere == "south") b = 7 - b;
  if (b == 0) return TXT_MOON_NEW;              // New;              0%  illuminated
  if (b == 1) return TXT_MOON_WAXING_CRESCENT;  // Waxing crescent; 25%  illuminated
  if (b == 2) return TXT_MOON_FIRST_QUARTER;    // First quarter;   50%  illuminated
  if (b == 3) return TXT_MOON_WAXING_GIBBOUS;   // Waxing gibbous;  75%  illuminated
  if (b == 4) return TXT_MOON_FULL;             // Full;            100% illuminated
  if (b == 5) return TXT_MOON_WANING_GIBBOUS;   // Waning gibbous;  75%  illuminated
  if (b == 6) return TXT_MOON_THIRD_QUARTER;    // Third quarter;   50%  illuminated
  if (b == 7) return TXT_MOON_WANING_CRESCENT;  // Waning crescent; 25%  illuminated
  return "";
}
//#########################################################################################
void arrow(int x, int y, int asize, float aangle, int pwidth, int plength) {
  float dx = (asize + 28) * cos((aangle - 90) * PI / 180) + x; // calculate X position
  float dy = (asize + 28) * sin((aangle - 90) * PI / 180) + y; // calculate Y position
  float x1 = 0;           float y1 = plength;
  float x2 = pwidth / 2;  float y2 = pwidth / 2;
  float x3 = -pwidth / 2; float y3 = pwidth / 2;
  float angle = aangle * PI / 180;
  float xx1 = x1 * cos(angle) - y1 * sin(angle) + dx;
  float yy1 = y1 * cos(angle) + x1 * sin(angle) + dy;
  float xx2 = x2 * cos(angle) - y2 * sin(angle) + dx;
  float yy2 = y2 * cos(angle) + x2 * sin(angle) + dy;
  float xx3 = x3 * cos(angle) - y3 * sin(angle) + dx;
  float yy3 = y3 * cos(angle) + x3 * sin(angle) + dy;
  display.fillTriangle(xx1, yy1, xx3, yy3, xx2, yy2, GxEPD_BLACK);
}
//#########################################################################################
void DisplayWXicon(int x, int y, String IconName, bool IconSize) {
  Serial.println(IconName);
  if      (IconName == "01d" || IconName == "01n")  Sunny(x, y, IconSize, IconName);
  else if (IconName == "02d" || IconName == "02n")  MostlySunny(x, y, IconSize, IconName);
  else if (IconName == "03d" || IconName == "03n")  Cloudy(x, y, IconSize, IconName);
  else if (IconName == "04d" || IconName == "04n")  MostlyCloudy(x, y, IconSize, IconName);
  else if (IconName == "09d" || IconName == "09n")  ChanceRain(x, y, IconSize, IconName);
  else if (IconName == "10d" || IconName == "10n")  Rain(x, y, IconSize, IconName);
  else if (IconName == "11d" || IconName == "11n")  Tstorms(x, y, IconSize, IconName);
  else if (IconName == "13d" || IconName == "13n")  Snow(x, y, IconSize, IconName);
  else if (IconName == "50d")                       Haze(x, y, IconSize, IconName);
  else if (IconName == "50n")                       Fog(x, y, IconSize, IconName);
  else                                              Nodata(x, y, IconSize, IconName);
}
//#########################################################################################
uint8_t StartWiFi() {
  Serial.print("\r\nConnecting to: "); Serial.println(String(ssid));
  IPAddress dns(8, 8, 8, 8); // Google DNS
  WiFi.disconnect();
  WiFi.mode(WIFI_STA); // switch off AP
  WiFi.begin(ssid, password);
  unsigned long start = millis();
  uint8_t connectionStatus;
  bool AttemptConnection = true;
  while (AttemptConnection) {
    connectionStatus = WiFi.status();
    if (millis() > start + 15000) { // Wait 15-secs maximum
      AttemptConnection = false;
    }
    if (connectionStatus == WL_CONNECTED || connectionStatus == WL_CONNECT_FAILED) {
      AttemptConnection = false;
    }
    delay(50);
  }
  if (connectionStatus == WL_CONNECTED) {
    wifi_signal = WiFi.RSSI(); // Get Wifi Signal strength now, because the WiFi will be turned off to save power!
    Serial.println("WiFi connected at: " + WiFi.localIP().toString());
  }
  else Serial.println("WiFi connection *** FAILED ***");
  return connectionStatus;
}
//#########################################################################################
void StopWiFi() {
  WiFi.disconnect();
  WiFi.mode(WIFI_OFF);
}
//#########################################################################################
boolean SetupTime() {
  configTime(gmtOffset_sec, daylightOffset_sec, ntpServer, "time.nist.gov"); //(gmtOffset_sec, daylightOffset_sec, ntpServer)
  setenv("TZ", Timezone, 1);  //setenv()adds the "TZ" variable to the environment with a value TimeZone, only used if set to 1, 0 means no change
  tzset(); // Set the TZ environment variable
  delay(100);
  bool TimeStatus = UpdateLocalTime();
  return TimeStatus;
}
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
